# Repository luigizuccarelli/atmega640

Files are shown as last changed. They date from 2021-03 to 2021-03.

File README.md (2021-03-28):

# atmega640 iot-controller

## Overview 

The software used in this project cover
- xl335 accelerometer
- ds18b20 digital temperature sensor

It ouptuts data to the serial usb /dev/ttyUSB0 (which can be configured)
The main loop waits for a char from the serial port and then takes a mesurement of both sensors

## Interface
As mentioned all connectovity is from and to the serial usb device
This gives a good layer of abstraction (not dependant on specific pinouts)
The controller is an omega onion + written in golang
Data transferred for the temperature probe and accelerometer are int values, converiosn to float takes place at the golang omega contoller

## AVR fuses
Internal clock divide by 8 startup time set to max , spi and jtag enable, bootsize set to 00

```bash
-U lfuse:w:0x62:m -U hfuse:w:0x99:m -U efuse:w:0xff:m
```

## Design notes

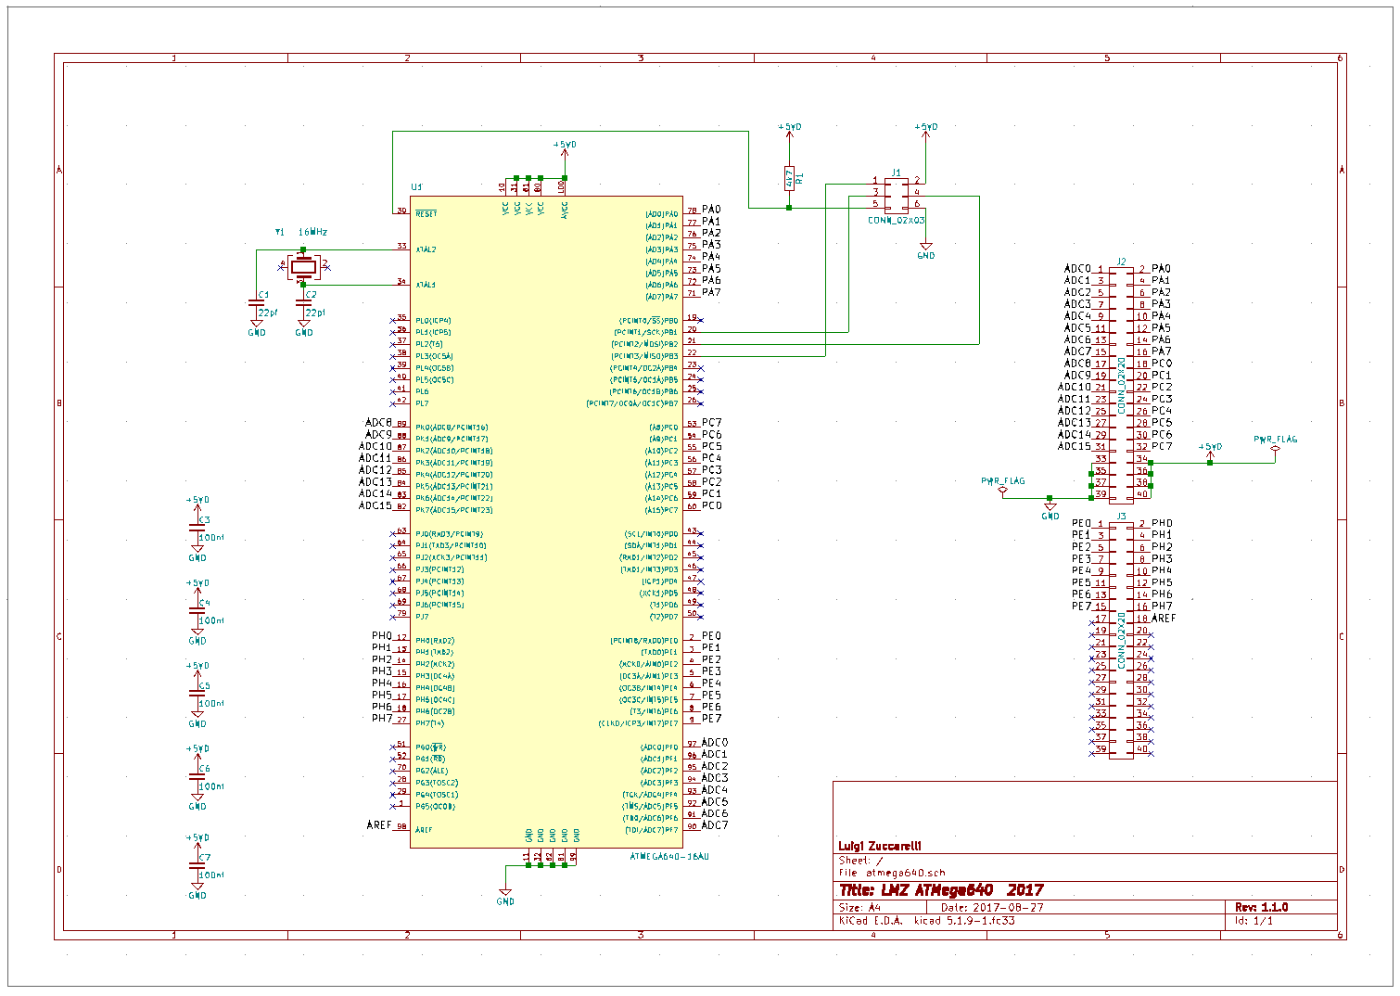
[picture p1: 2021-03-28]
schematic.png

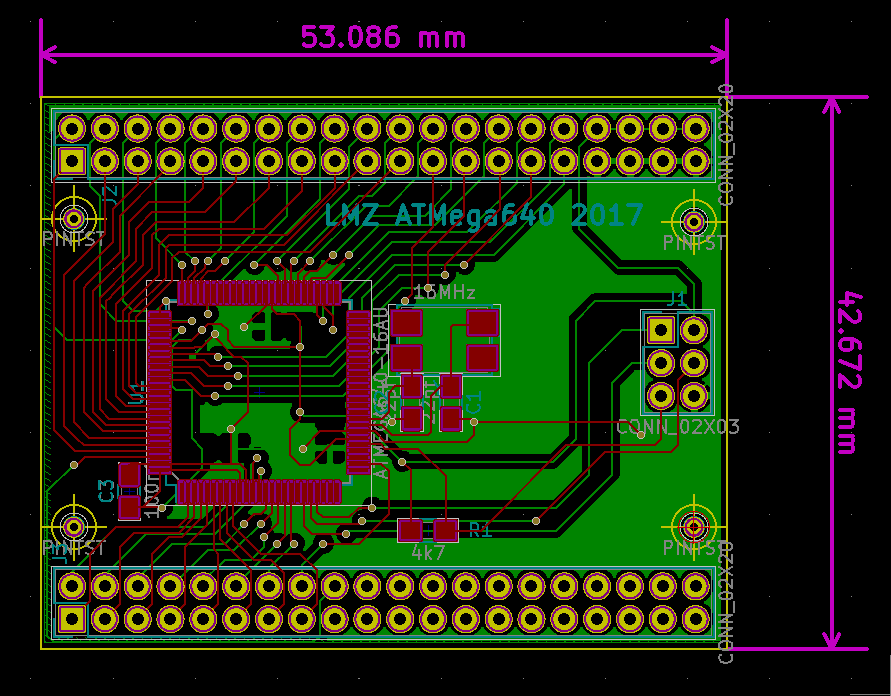
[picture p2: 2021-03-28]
pcb.png

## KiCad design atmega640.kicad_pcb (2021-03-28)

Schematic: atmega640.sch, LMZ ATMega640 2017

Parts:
C1, C2: 22pf; C_0805_HandSoldering
C3, C4, C5, C6, C7: 100nf; C_0805_HandSoldering
J1: CONN_02X03; Pin_Header_Straight_2x03_Pitch2.54mm
J2, J3: CONN_02X20; Pin_Header_Straight_2x20_Pitch2.54mm
R1: 4k7; R_0805_HandSoldering
U1: ATMEGA640-16AU; TQFP-100_14x14mm_Pitch0.5mm
Y1: 16MHz; Crystal_SMD_7050-4pin_7.0x5.0mm

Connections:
+5VD: C3.1, C4.1, C5.1, C6.1, C7.1, J1.2, J2.34, J2.36, J2.38, J2.40, R1.1, U1.10 (VCC), U1.31 (VCC), U1.61 (VCC), U1.80 (VCC), U1.100 (AVCC)
/ADC0: J2.1, U1.97 ((ADC0)PF0)
/ADC1: J2.3, U1.96 ((ADC1)PF1)
/ADC2: J2.5, U1.95 ((ADC2)PF2)
/ADC3: J2.7, U1.94 ((ADC3)PF3)
/ADC4: J2.9, U1.93 ((TCK/ADC4)PF4)
/ADC5: J2.11, U1.92 ((TMS/ADC5)PF5)
/ADC6: J2.13, U1.91 ((TD0/ADC6)PF6)
/ADC7: J2.15, U1.90 ((TDI/ADC7)PF7)
/ADC8: J2.17, U1.89 (PK0(ADC8/PCINT16))
/ADC9: J2.19, U1.88 (PK1(ADC9/PCINT17))
/ADC10: J2.21, U1.87 (PK2(ADC10/PCINT18))
/ADC11: J2.23, U1.86 (PK3(ADC11/PCINT19))
/ADC12: J2.25, U1.85 (PK4(ADC12/PCINT20))
/ADC13: J2.27, U1.84 (PK5(ADC13/PCINT21))
/ADC14: J2.29, U1.83 (PK6(ADC14/PCINT22))
/ADC15: J2.31, U1.82 (PK7(ADC15/PCINT23))
/AREF: J3.18, U1.98 (AREF)
/PA0: J2.2, U1.78 ((AD0)PA0)
/PA1: J2.4, U1.77 ((AD1)PA1)
/PA2: J2.6, U1.76 ((AD2)PA2)
/PA3: J2.8, U1.75 ((AD3)PA3)
/PA4: J2.10, U1.74 ((AD4)PA4)
/PA5: J2.12, U1.73 ((AD5)PA5)
/PA6: J2.14, U1.72 ((AD6)PA6)
/PA7: J2.16, U1.71 ((AD7)PA7)
/PC0: J2.18, U1.60 ((A15)PC7)
/PC1: J2.20, U1.59 ((A14)PC6)
/PC2: J2.22, U1.58 ((A13)PC5)
/PC3: J2.24, U1.57 ((A12)PC4)
/PC4: J2.26, U1.56 ((A11)PC3)
/PC5: J2.28, U1.55 ((A10)PC2)
/PC6: J2.30, U1.54 ((A9)PC1)
/PC7: J2.32, U1.53 ((A8)PC0)
/PE0: J3.1, U1.2 ((PCINT8/RXD0)PE0)
/PE1: J3.3, U1.3 ((TXD0)PE1)
/PE2: J3.5, U1.4 ((XCK0/AIN0)PE2)
/PE3: J3.7, U1.5 ((OC3A/AIN1)PE3)
/PE4: J3.9, U1.6 ((OC3B/INT4)PE4)
/PE5: J3.11, U1.7 ((OC3C/INT5)PE5)
/PE6: J3.13, U1.8 ((T3/INT6)PE6)
/PE7: J3.15, U1.9 ((CLKO/ICP3/INT7)PE7)
/PH0: J3.2, U1.12 (PH0(RXD2))
/PH1: J3.4, U1.13 (PH1(TXD2))
/PH2: J3.6, U1.14 (PH2(XCK2))
/PH3: J3.8, U1.15 (PH3(OC4A))
/PH4: J3.10, U1.16 (PH4(OC4B))
/PH5: J3.12, U1.17 (PH5(OC4C))
/PH6: J3.14, U1.18 (PH6(OC2B))
/PH7: J3.16, U1.27 (PH7(T4))
GND: C1.2, C2.2, C3.2, C4.2, C5.2, C6.2, C7.2, J1.6, J2.33, J2.35, J2.37, J2.39, U1.11 (GND), U1.32 (GND), U1.62 (GND), U1.81 (GND), U1.99 (GND)
unnamed: C1.1, U1.33 (XTAL2), Y1.1
unnamed: C2.1, U1.34 (XTAL1), Y1.3
unnamed: J1.1, U1.22 ((PCINT3/MISO)PB3)
unnamed: J1.3, U1.20 ((PCINT1/SCK)PB1)
unnamed: J1.4, U1.21 ((PCINT2/MOSI)PB2)
unnamed: J1.5, R1.2, U1.30 (~RESET)

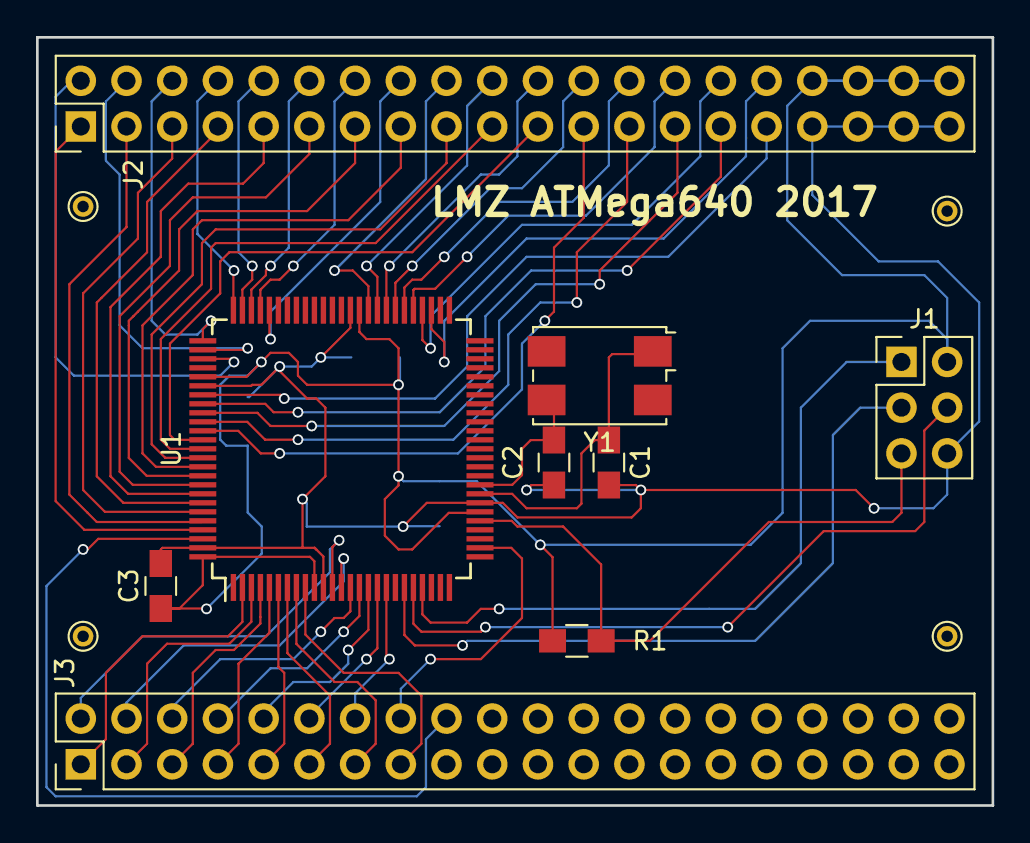
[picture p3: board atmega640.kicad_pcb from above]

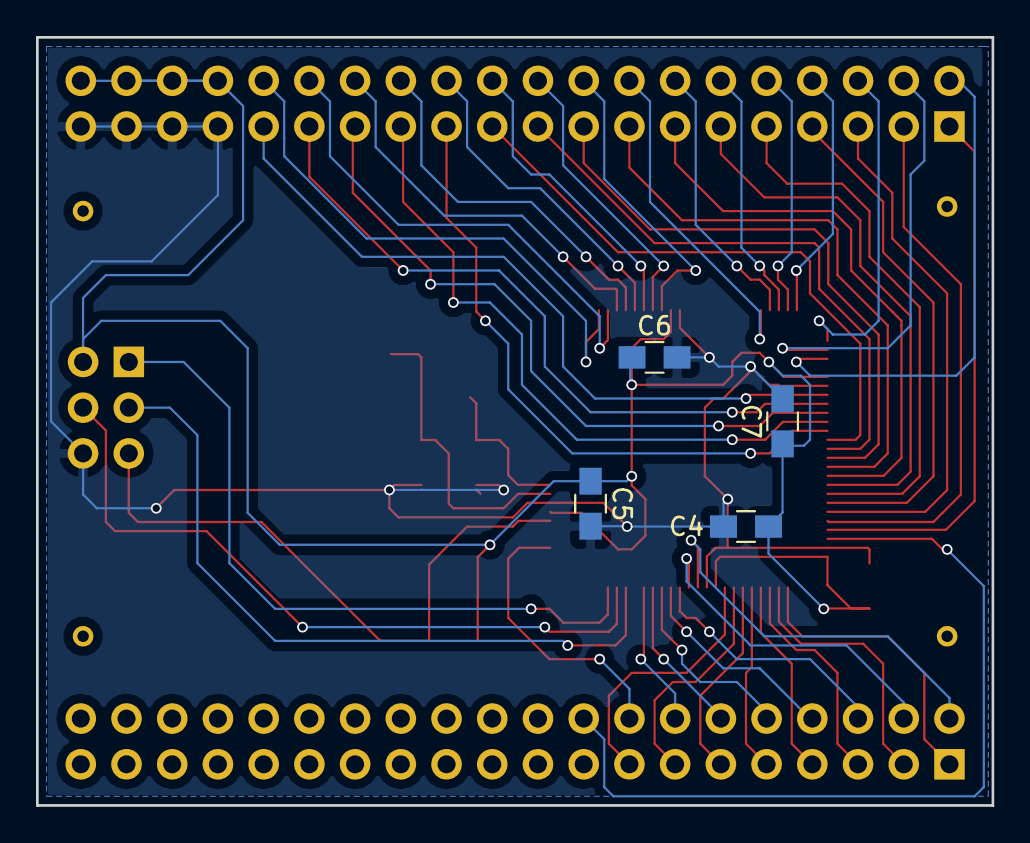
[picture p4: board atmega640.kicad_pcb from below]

Board: 2 copper layers, 53.1 x 42.7 mm, 13 parts (4 on the bottom side), 57 nets.

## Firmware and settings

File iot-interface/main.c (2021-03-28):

#include <avr/io.h>
#include <util/delay.h>
#include <stdlib.h>
#include <avr/interrupt.h>
#include <stdio.h>

#include "ds18b20.h"

// definition of registers see atmega docs page 218
// UCSRnA - 7 6 5 4 3 2 1 0 - used for reading flags
//          
// UCSRnB - 7 6 5 4 3 2 1 0 - set Rxen and Txen 
//          0 0 0 1 1 0 0 0
//
// UCSRnC - 7 6 5 4 3 2 1 0 - asynchronous, set 8 bit, 1 stop bit, no parity
//          0 0 0 0 0 1 1 0 

void uartInit(void)
{
  // DDRE   = 0b00000000;
  // double baud rate
  UCSR0A = 0b00000010;
  UCSR0B = 0b00011000;
  UCSR0C = 0b00000110;
  //set to 12 - baud rate will be 9600
  UBRR0L = 0b00001100; 
  UBRR0H = 0b00000000;
}

unsigned char uartRxChar(void) {
  while ((UCSR0A & (1 << RXC0)) == 0);
  return(UDR0);			
}

void uartTxChar(char ch) {
  while (! (UCSR0A & (1<<UDRE0)));	
  UDR0 = ch ;
}

void uartTxString(char *str) {
  unsigned char j=0;

  while (str[j]!=0)	{
    uartTxChar(str[j]);	
    j++;
  }
}

void adcInit(void) {
  DIDR0 = 0x00;
  // set PA0-PA7 to input
  // DDRA = 0x00;
  // enable ADC with freq/128  
  ADCSRA = 0x86;
  // free running  
  ADCSRB = 0x00;  
  // set Vref at Vcc and ADC channel 0
  ADMUX  = 0b01000000;  
}

int adcRead(char channel) {
  int hi,lo;

  ADMUX = 0b01000000 | (0b00000111 & channel);
  _delay_us(500);
  // start conversion
  ADCSRA |= (1<<ADSC); 
  // wait for conversion to complete
  while (!(ADCSRA & (1<<ADSC))){}
  _delay_us(500);
  lo = ADCL;
  hi = ADCH;
  return (hi << 8) + lo;
}

int main(void) {
  int t,x,y,z = 0;
  char buf[50];

  uartInit();
  adcInit();

  _delay_ms(100);
  sei();

  while(1) {
    // wait to start measurement
    uartRxChar();
    _delay_ms(10);
    // take accelerometer reading for x,y,z co ordinates
    x = adcRead(0);
    y = adcRead(1);
    z = adcRead(2);
    // take dsb1820 temp
    t = ds18b20Gettemp();
    sprintf(buf,"%d %d %d %d\n\r",t,x,y,z);
    // send to serial usb
    uartTxString(buf);	
  }
  return 0;  
}

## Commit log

2021-03-28 Initial commit
    Why:
    * IOT controller for gmd
    Solution:
    * Kicad design files and c code for sensors
    Task link:
    * NA
    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
    [atmega640-2020-11-21-13-11-35.sch, atmega640-2021-03-28-17-30-20.sch, atmega640.kicad_pcb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]
2021-03-28 Updated README
    Validtion steps:
    Author:
    * Luigi Zuccarell
    Date:
    * 28/03/2021 17:50
    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
